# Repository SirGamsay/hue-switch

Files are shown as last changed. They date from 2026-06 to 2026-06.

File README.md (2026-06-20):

# Hue Switch

A minimal Bluetooth (BLE) push-button that toggles a Philips Hue lamp — built around an **ESP32-C3** and [NimBLE-Arduino](https://github.com/h2zero/NimBLE-Arduino).

No bridge, no Wi-Fi, no cloud. The microcontroller talks directly to the lamp's built-in BLE radio.

## How it works

Pressing the button triggers a BLE connection to the Hue lamp. The firmware reads the current on/off state from the lamp's GATT characteristic and writes the opposite value back.

- 2 blinks on startup — ready
- LED solid during connection attempt
- 3 blinks — toggled successfully
- 5 fast blinks — connection or write failed

## Hardware

| Part | Notes |
|---|---|
| ESP32-C3-DevKitM-1 | any ESP32-C3 board works |
| Momentary push button | wired between GPIO6 and GND |
| LED + 220 Ω resistor | GPIO4 → resistor → LED → GND |
| Philips Hue bulb | must support BLE (gen 3+, firmware ≥ 1.50) |

**GPIO overview:**

| GPIO | Function |
|---|---|
| 2 | Fake GND (output LOW — frees a GND pad) |
| 4 | External LED (active HIGH) |
| 6 | Button (INPUT\_PULLUP) |
| 8 | Onboard LED for debugging (active LOW) |

## Enclosure

The `cad/` directory contains FreeCAD source files and STL exports for a small printed enclosure.

## Configuration

Open `src/main.cpp` and adjust the defines at the top:

```cpp
#define HUE_MAC    "xx:xx:xx:xx:xx:xx"  // BLE MAC of your Hue lamp
#define BUTTON_PIN 6
#define LED_EXT    4
#define LED_INT    8
#define FAKE_GND   2
```

To find your lamp's MAC, flash the `ble-scan` environment (see below) and look for a device whose name contains "Hue".

## Build & Flash

Requires [PlatformIO](https://platformio.org/).

```bash
# Flash the main firmware
pio run -e hue-controller -t upload

# Scan for BLE devices (to find your lamp's MAC)
pio run -e ble-scan -t upload && pio device monitor

# Test the button wiring
pio run -e button-test -t upload && pio device monitor
```

## First pairing

The ESP32-C3 bonds with the lamp on the first connection using "just works" BLE pairing (no PIN). The bond is stored in NVS flash and reused on subsequent connections. If pairing fails, erase the flash once with:

```bash
pio run -e hue-controller -t erase
```

## License

MIT

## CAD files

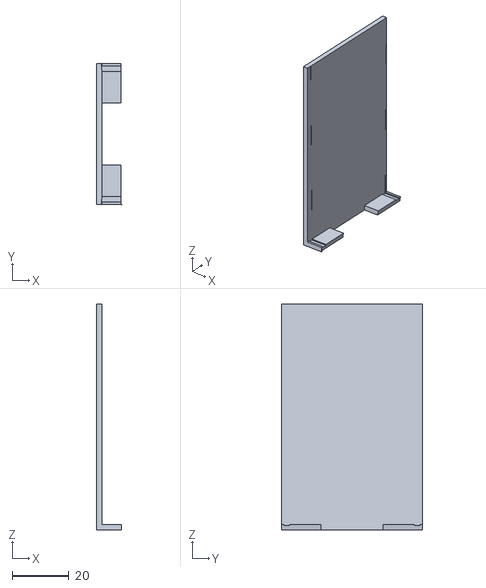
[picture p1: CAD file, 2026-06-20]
cad/Base plate.stl
9.00 x 50.0 x 80.0

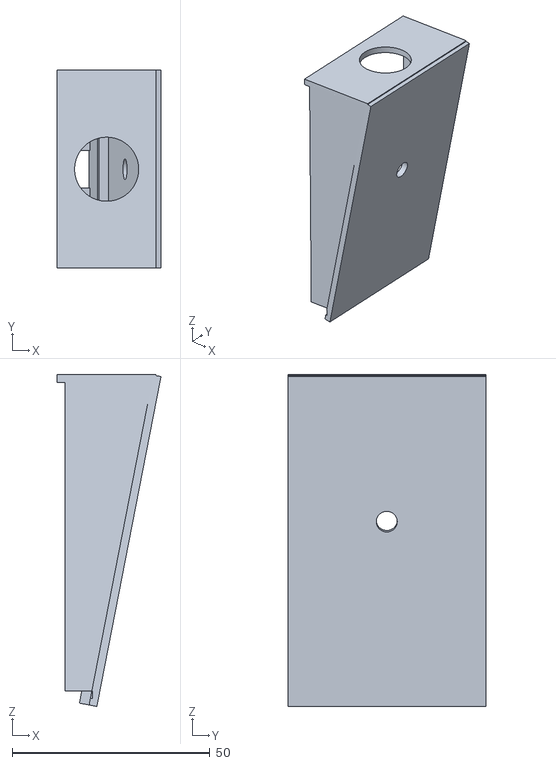
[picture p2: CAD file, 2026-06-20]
cad/Sides.stl
26.3 x 50.0 x 84.0

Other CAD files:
cad/hue_switch_enclosure.FCStd

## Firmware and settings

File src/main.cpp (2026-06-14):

#include <Arduino.h>
#include <NimBLEDevice.h>

// ============================================================
//  KONFIGURATION
// ============================================================
#define HUE_MAC    "da:0d:03:84:73:0d"
#define BUTTON_PIN 6
#define LED_EXT    4   // externe LED: GPIO4 → 220Ω → LED → GND  (active HIGH)
#define LED_INT    8   // onboard LED (active LOW, Debugging)
#define FAKE_GND   2   // kein freier GND-Pin → GPIO2 als GND-Ersatz (OUTPUT LOW)
// ============================================================

static NimBLEUUID svcUUID("932c32bd-0000-47a2-835a-a8d455b859dd");
static NimBLEUUID pwrUUID("932c32bd-0002-47a2-835a-a8d455b859dd");

static void ledOn() {
    digitalWrite(LED_EXT, HIGH);
    digitalWrite(LED_INT, LOW);
}
static void ledOff() {
    digitalWrite(LED_EXT, LOW);
    digitalWrite(LED_INT, HIGH);
}
static void ledBlink(int n, int ms = 80) {
    for (int i = 0; i < n; i++) {
        ledOn();  delay(ms);
        ledOff(); delay(ms);
    }
}

class SecurityCB : public NimBLESecurityCallbacks {
    void onAuthenticationComplete(ble_gap_conn_desc* desc) override {}
    bool onConfirmPIN(uint32_t pin) override { return true; }
    uint32_t onPassKeyRequest() override { return 0; }
    void onPassKeyNotify(uint32_t pass_key) override {}
    bool onSecurityRequest() override { return true; }
};

void toggleLight() {
    NimBLEAddress addr(HUE_MAC, BLE_ADDR_RANDOM);
    NimBLEClient* client = NimBLEDevice::createClient();
    ledOn();

    if (!client->connect(addr)) {
        NimBLEDevice::deleteClient(client);
        ledBlink(5, 60);
        return;
    }

    delay(200);
    if (!client->secureConnection()) {
        client->disconnect();
        NimBLEDevice::deleteClient(client);
        ledBlink(5, 60);
        return;
    }

    NimBLERemoteService* svc = client->getService(svcUUID);
    if (!svc) {
        client->disconnect();
        NimBLEDevice::deleteClient(client);
        ledBlink(5, 60);
        return;
    }

    NimBLERemoteCharacteristic* pwr = svc->getCharacteristic(pwrUUID);
    if (!pwr) {
        client->disconnect();
        NimBLEDevice::deleteClient(client);
        ledBlink(5, 60);
        return;
    }

    uint8_t current = 0;
    std::string raw = pwr->readValue();
    if (!raw.empty()) current = static_cast<uint8_t>(raw[0]);

    uint8_t next = current ? 0x00 : 0x01;
    bool written = pwr->writeValue(&next, 1, false);

    client->disconnect();
    NimBLEDevice::deleteClient(client);
    delay(1000);

    written ? ledBlink(3, 100) : ledBlink(5, 60);
}

static bool lastBtn        = HIGH;
static uint32_t lastChange = 0;

void setup() {
    pinMode(FAKE_GND, OUTPUT);
    digitalWrite(FAKE_GND, LOW);
    pinMode(BUTTON_PIN, INPUT_PULLUP);
    pinMode(LED_EXT, OUTPUT);
    pinMode(LED_INT, OUTPUT);
    ledOff();

    NimBLEDevice::init("HueSwitch");
    NimBLEDevice::setPower(ESP_PWR_LVL_P3);
    NimBLEDevice::setSecurityAuth(BLE_SM_PAIR_AUTHREQ_BOND);
    NimBLEDevice::setSecurityIOCap(BLE_HS_IO_NO_INPUT_OUTPUT);
    NimBLEDevice::setSecurityCallbacks(new SecurityCB());

    ledBlink(2, 150);  // Startbestätigung
}

void loop() {
    bool btn = digitalRead(BUTTON_PIN);
    uint32_t now = millis();

    if (btn != lastBtn && (now - lastChange) > 50) {
        lastChange = now;
        lastBtn    = btn;
        if (btn == LOW) toggleLight();
    }
    delay(10);
}

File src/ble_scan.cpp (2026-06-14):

#include <Arduino.h>
#include <NimBLEDevice.h>

void setup() {
    Serial.begin(115200);
    delay(500);
    Serial.println("\n=== BLE Scan ===");

    NimBLEDevice::init("");
    NimBLEScan* scan = NimBLEDevice::getScan();
    scan->setActiveScan(true);
    scan->setInterval(100);
    scan->setWindow(99);

    Serial.println("Scanne 10 Sekunden …");
    NimBLEScanResults results = scan->start(10, false);

    Serial.printf("\n%d Gerät(e) gefunden:\n", results.getCount());
    for (int i = 0; i < results.getCount(); i++) {
        NimBLEAdvertisedDevice dev = results.getDevice(i);
        Serial.printf("  [%d] %s  RSSI: %d  Name: %s\n",
            i,
            dev.getAddress().toString().c_str(),
            dev.getRSSI(),
            dev.getName().c_str());
    }
    Serial.println("\nFertig. Reset für neuen Scan.");
}

void loop() {}

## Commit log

2026-06-14 Init Hue Controller
    [Base plate.stl, Sides.stl, Unnamed.FCStd]
2026-06-20 Prepare repo for public GitHub release
    - Add README with hardware pinout, build instructions, and pairing notes
    - Rename FreeCAD file to hue_switch_enclosure.FCStd
    - Refresh STL exports
    - Extend .gitignore with *.FCBak; remove FCBak backup from tracking
    [Base plate.stl, Sides.stl, hue_switch_enclosure.FCStd]
